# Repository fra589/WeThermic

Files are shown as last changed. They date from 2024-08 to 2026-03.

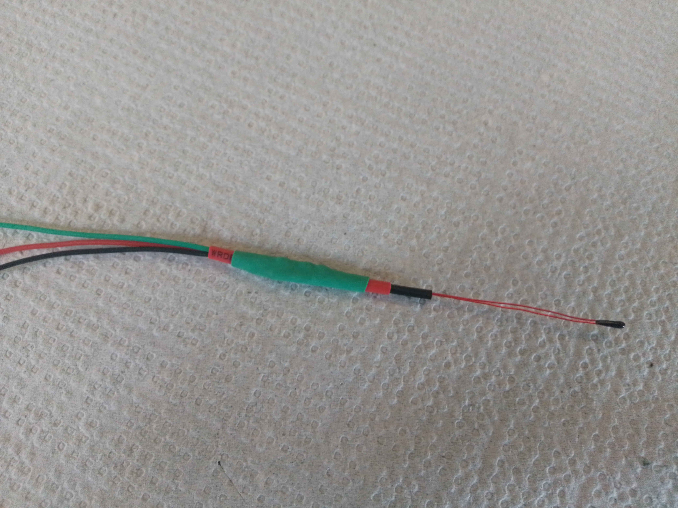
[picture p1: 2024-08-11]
images/IMG_20240811_103702.jpg

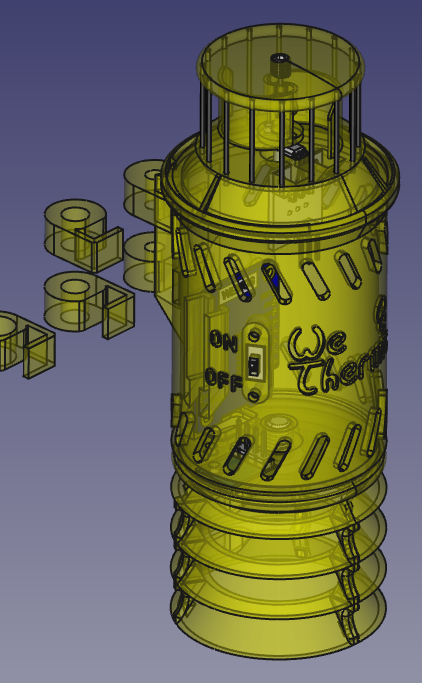
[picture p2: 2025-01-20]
images/freecad02.png

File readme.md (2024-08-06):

<h1 align='center'>WeThermic Free Flight Thermal Detector</h1>
<p>
Station météo indiquant la vitesse du vent, la température et la pression atmosphérique ainsi que l'affichage des courbes correspondantes sur un navigateur web, via un réseau WiFi, pour aider à la détection d'ascendances thermiques en modèle réduit de vol libre.
</p>
<p>
Weather station indicating wind speed, temperature and atmospheric pressure as well as displaying the corresponding curves on a web browser, via a WiFi network, to help detect thermal ascents in free flight model aircraft.  
</p>
<table>
<tr>
<td>
<b>Matériel utilisé :</b>
<ul>
<li>Boitier imprimé en 3D,</li>
<li>1 x Carte microcontrôleur WiFi ESP8266 Wemos D1 mini,</li>
<li>1 x Capteur de vent :</li>
<ul>
<li>2 x Aimants néodyme Ø2x2,</li>
<li>1 x Capteur à effet Hall KY-003,</li>
</ul>
<li>1 x Capteur de température et pression Bosch BMP180,</li>
<li>1 x Termistance 10K MF52B B3435 1%,</li>
<li>1 x Résistance 10KΩ 1/4W 1%,</li>
<li><s>1 x écran OLED I2C SSD1306, 0.96 Pouce, 128 x 64 Pixel.</li></s></li>
</ul>
</td>
<td>
<b>Hardware:</b>
<ul>
<li>3D printed case</li>
<li>1 x Wemos D1 mini ESP8266 WiFi microcontroller card,</li>
<li>1 x Wind sensor:</li>
<ul>
<li>2 x Ø2x2 neodymium magnets,</li>
<li>1 x Hall effect sensor KY-003,</li>
</ul>
<li>1 x Bosch BMP180 temperature and pressure sensor,</li>
<li>1 x Termistor 10K MF52B B3435 1%,</li>
<li>1 x Resistance 10KΩ 1/4W 1%,</li>
<li><s>1 x I2C SSD1306 OLED screen, 0.96 Inch, 128x64 Pixel.</s></li>
</ul>
</td>
</tr>
<tr>
<td>
<b>Prérequis logiciels :</b>
<p><br />
Pour construction à partir des sources :
<ul>
<li><a href="https://www.arduino.cc/en/software">Environnement de développement Arduino v1.8.19</a>,</li>
<ul>
<li><a href="https://github.com/esp8266/Arduino">Noyau Arduino pour puce WiFi ESP8266</a>,</li>
<li><a href="https://github.com/earlephilhower/arduino-esp8266littlefs-plugin">Téléchargeur système de fichiers ESP8266 LittleFS</a>,</li>
<li><s><a href="https://github.com/adafruit/Adafruit_SSD1306">Adafruit_SSD1306</a>,</s></li>
<li><a href="https://github.com/sparkfun/BMP180_Breakout_Arduino_Library">BMP180_Breakout_Arduino_Library </a>,</li>
</ul>
</p>
</ul>
<p>
Flashage a partir des realeases binaires (Windows only):
<ul>
<li><a href="https://www.espressif.com/en/support/download/other-tools">Flash Download Tools</a>,</li>
<li><a href="https://github.com/fra589/WeThermic/releases">Dernier firmware (WeThermic.firmware_v<span>_X.Y.ZZZZZZ</span>.bin)</a></li>
<li><a href="https://github.com/fra589/WeThermic/releases">Dernière application (WeThermic.application_v<span>_X.Y.ZZZZZZ</span>.bin)</a></li>
</ul>
</p>
</td>
<td>
<b>Requisites software:</b>
<p><br />
To build from sources:
<ul>
<li><a href="https://www.arduino.cc/en/software">Arduino ide v1.8.19</a>,</li>
<ul>
<li><a href="https://github.com/esp8266/Arduino">Arduino core for ESP8266 WiFi chip</a>,
<li><a href="https://github.com/earlephilhower/arduino-esp8266littlefs-plugin">Arduino ESP8266 LittleFS Filesystem Uploader</a>,</li>
<li><s><a href="https://github.com/adafruit/Adafruit_SSD1306">Adafruit_SSD1306</a>,</s></li>
<li><a href="https://github.com/sparkfun/BMP180_Breakout_Arduino_Library">BMP180_Breakout_Arduino_Library </a>,</li>
</ul>
</p>
</ul>
<p>
To flash from binary realeases (Windows only):
<ul>
<li><a href="https://www.espressif.com/en/support/download/other-tools">Flash Download Tools</a>,</li>
<li><a href="https://github.com/fra589/WeThermic/releases">Latest firmware (WeThermic.firmware_v<span>_X.Y.ZZZZZZ</span>.bin)</a></li>
<li><a href="https://github.com/fra589/WeThermic/releases">Latest application (WeThermic.application_v<span>_X.Y.ZZZZZZ</span>.bin)</a></li>
</ul>
</p>
</td>
</tr>
</table>
<p>
Développement en cours, de nouvelles version possibles à tout moment, pas forcément sans bugs :-)
</p>
<p>
Development in progress, new versions possible at any time, not necessarily without bugless :-)
</p>
<p align='center'>
<a href='https://github.com/fra589/WeThermic/wiki'><B>Wiki documentation in progress...</B></a>
</p>

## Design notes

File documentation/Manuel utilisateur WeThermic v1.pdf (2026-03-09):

## Version 1.0

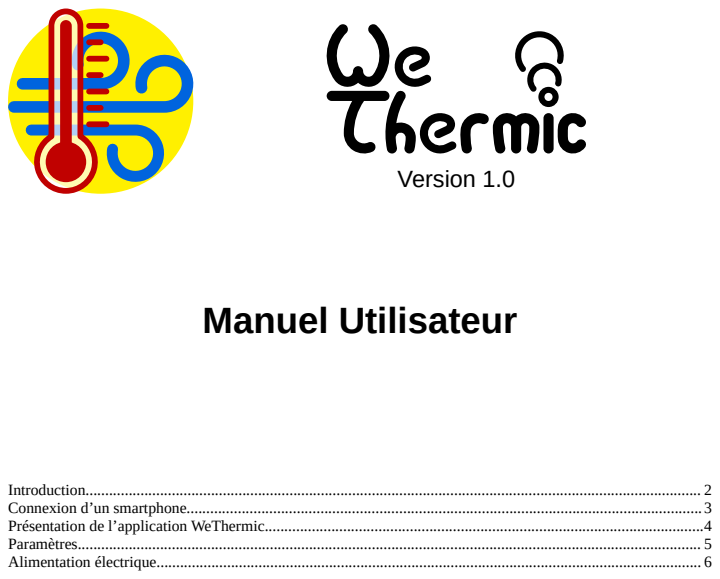
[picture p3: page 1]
Manuel Utilisateur

## Introduction

Le projet WeThermic est un projet visant à créer une station météo capable d’aider les aéromodélistes pratiquant le vol libre dans la détection des ascendances.
La station météo WeThermic utilise des éléments bon marché et facile à se procurer et ne nécessitant pas de travaux important et/ou compliqués d’un point de vue des compétences en électronique.
La station météo est capable de fournir les courbes de vitesse du vent, température et pression atmosphérique sur une durée de 5, 10 ou 20 minutes avec une résolution respectivement de 0,5, 1 ou 2 secondes.
Les courbes peuvent être affichées avec un smartphone, une tablette ou tout autre équipement informatique capable de se connecter au point d’accès wifi que constitue la station, et de communiquer avec elle au travers un navigateur web.

## Connexion d’un smartphone

Les copies d’écran de cette notice ont été réalisées à l’aide d’un téléphone sous Android version 13. Cela peut ne pas correspondre exactement à votre téléphone, en cas de différences, se référer à la documentation de votre téléphone ou équipement.

Sur votre téléphone, ouvrez l’écran de configuration du wifi.
Quelques instant après avoir alimenté la station météo, vous devriez la voir apparaître dans la liste des réseaux disponibles (Figure 1).
Le nom par défaut (SSID) de la station est « WeThermic_XX:XX:XX ». Ou XX:XX:XX est un code unique dépendant du processeur wifi de la carte. Par défaut, il s’agit d’un réseau wifi « ouvert » qui n’utilise pas de mot de passe pour se connecter.

Cliquez sur le SSID pour connecter votre téléphone à la station météo.
Lors de la connexion, le téléphone indique une connectivité limitée. Ce comportement est normal, dans la mesure ou la connexion wifi vers la station ne permet pas l’accès à Internet.
Cliquez sur le message qui indique la connexion limitée pour forcer la connexion même sans Internet (Figure 2), puis, validez le message qui s’affiche (Figure 3).
Vous pouvez également cocher la case « Ne plus demander pour ce réseau » afin que vos futures connexions se fassent directement.

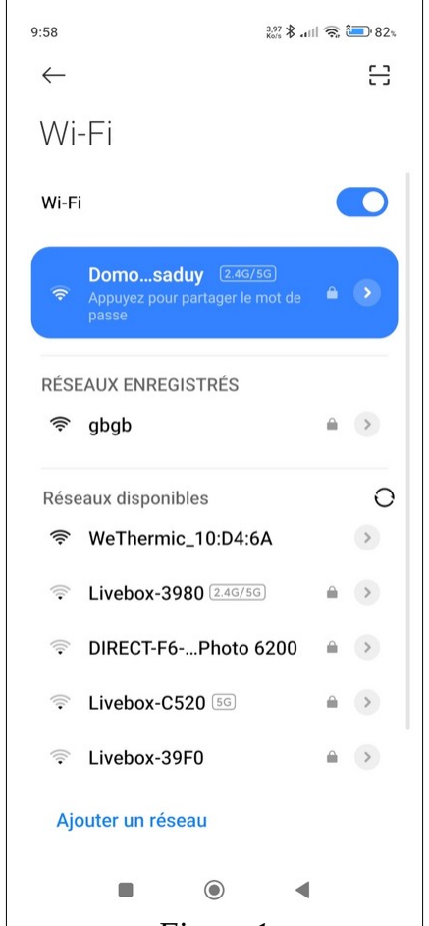
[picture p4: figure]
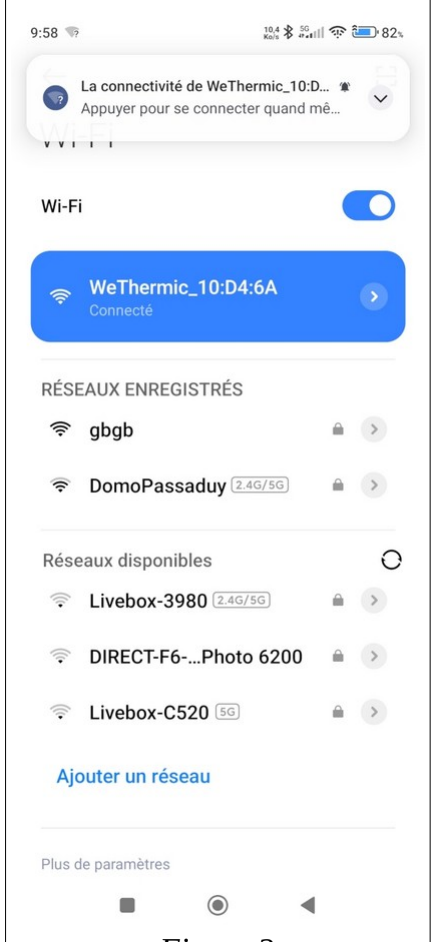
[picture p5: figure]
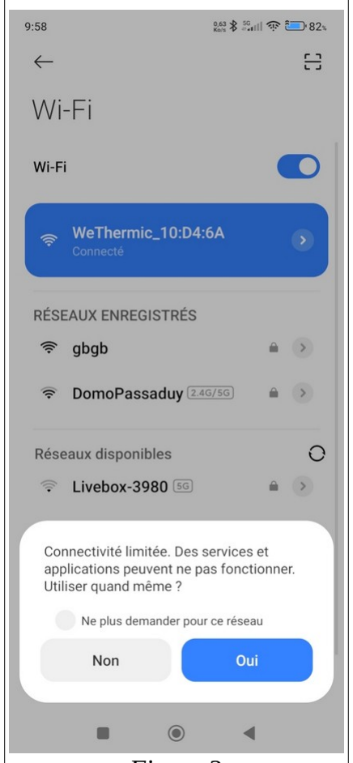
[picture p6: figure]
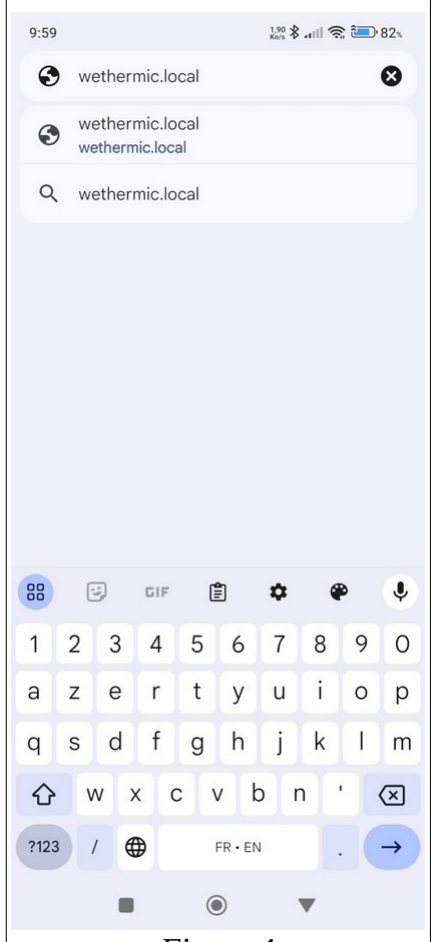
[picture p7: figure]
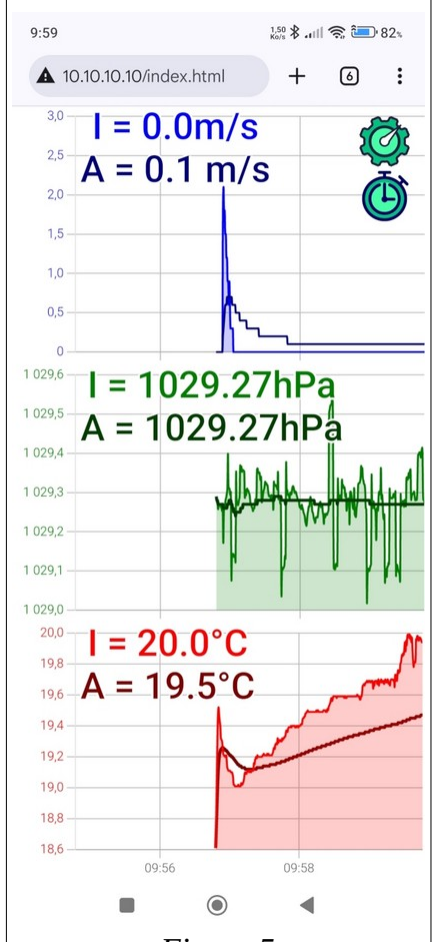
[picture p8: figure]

Une foi le wifi connecté, ouvrez votre navigateur Internet (Google Chrome par exemple) et tapez dans la barre d’adresse(Figure 4) :
http://wethermic.local

Le navigateur affiche maintenant la page d’accueil de la minuterie (Figure 5). Il est possible également, dans le cas ou le nom ne fonctionne pas avec votre smartphone, d’utiliser l’adresse IP : http://10.10.10.10 pour se connecter à la station.
Ajout d’une icône sur l’écran d’accueil de votre smartphone :

Cliquez sur les 3 points en haut à droite de l’écran du navigateur Google Chrome, puis, dans le menu qui s’ouvre, cliquez sur « Ajouter à l’écran d’accueil ».

Cette action ajoutera une icône d’accès directe au programme de la station météo sur votre écran d’accueil.

Figure 1 | Figure 2 | Figure 3 | Figure 4 | Figure 5

## Présentation de l’application WeThermic

Écran principal :

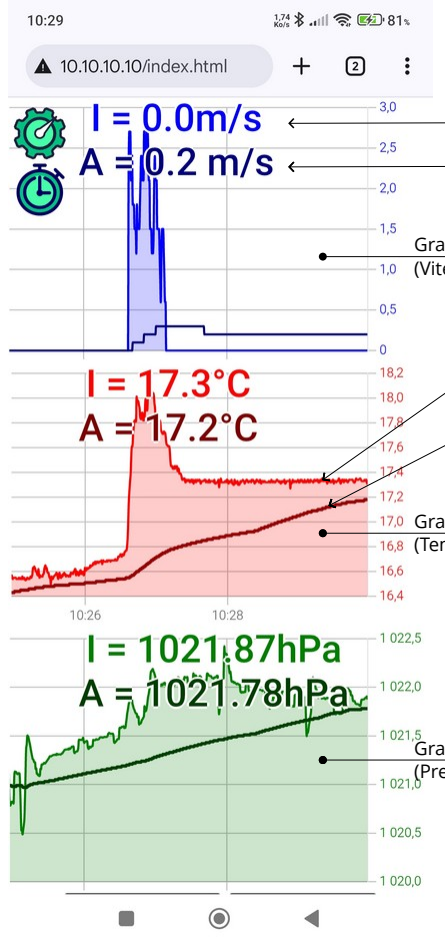
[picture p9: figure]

Faites glisser vers le haut permet de faire apparaître les 2 boutons suivants :

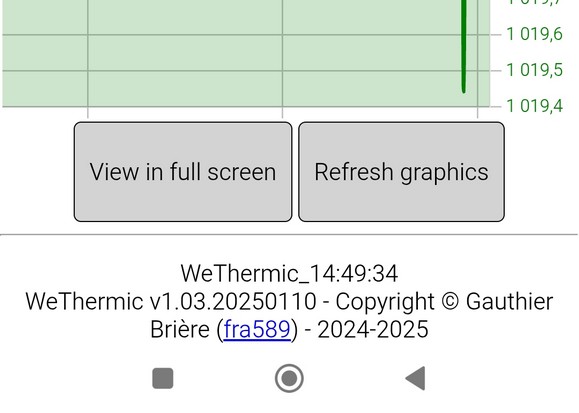
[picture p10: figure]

« View in full screen » : Bascule l’affichage en mode « plein écran ».

« Refresh graphics » : Recalcule et rafraîchi l’affichage de l’écran.

Un clic sur l’icône Permet d’afficher un compte à rebours de la fin du round. La valeur par défaut du compte à rebours est fixée à 7 minutes (durée standard d’un round de flyoff) :

Cliquez sur « | » pour démarrer le compte à rebours. Cliquez sur « | » pour l’arrêter.
Les icônes « | » et « | » qui s’affichent en même temps que le compte à rebours permettent de
désactiver ou d’activer un bip sonore qui marque toutes les minutes pendant le décompte du temps.

Graphique 1 (Upper graph)
(Vitesse du vent m/s par défaut)

Graphique 2 (Middle graph) (Température °C par défaut)

Graphique 3 (Bottom graph)
(Pression athmospherique (hPa) par défaut)

I : Valeur instantanée
A : Valeur moyenne

Courbe valeurs
insantanées
Courbe valeurs
moyennes

## Paramètres

Cliquez sur l’icône pour accéder à l’écran de paramétrage :

Les icônes en haut de l’écran de paramétrage servent à :

Fermer l’écran des paramètres,
Redémarrer la station météo,
Restaurer les paramètres d’origine par défaut de la station et de l’application.
- Au niveau du thème de couleur, vous pouvez choisir entre un thème foncé ( | )
ou un thème clair ( | ).

Cliquer sur les ronds de couleur permet de modifier la couleur des
éléments de manière indépendante :

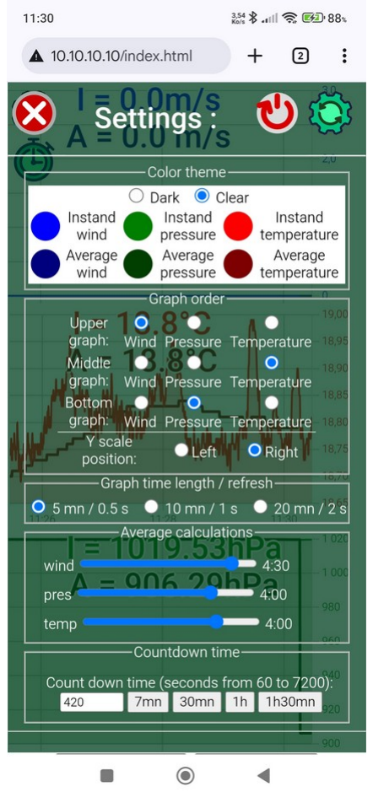
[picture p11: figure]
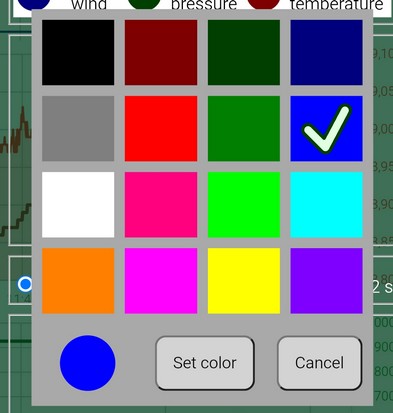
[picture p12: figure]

- Le cadre suivant « Graph order » permet de choisir l’ordre d’affichage des graphiques « Wind » (vent),
« Pressure » (pression atmosphérique) et « Temperature » (température) sur le graphique du haut, du milie ou du bas.
« Yscale position » « Left » / « Right » permet un chois de position des grilles d’échelle des graphiques respectivement à gauche ou à droite.

Le paramètre « Graph time length / refresh » définit la durée du graphique affichées, au choix :
- 5 minutes avec un taux de rafraîchissement de 0,5 seconde,
- 10 minutes avec un taux de rafraîchissement de 1 seconde,
- 20 minutes avec un taux de rafraîchissement de 2 seconds.

« Average calculations » permet de choisir la durée sur laquelle sont calculées les valeurs de la courbe moyenne. Cette durée est définie indépendamment pour chaque courbe wind (vent), pres (pression atmosphérique) ou temp (température). Les valeurs admises vont de 30 secondes à 5 minutes par pas de 30 secondes.

Le cadre « Countdown time » permet de définir la durée du compte à rebours. La zone de texte à gauche permet de saisir n’importe quelle valeur, exprimées en secondes. Les boutons à droite de cette zone de texte permettent d’entrer directement les valeur standards de 7 minutes, 30 minutes, 1 heure ou 1 heure et demi.

Faire glisser l’affichage vers le haut permet d’accéder à la configuration du réseau wifi de la station météo :

La première zone de texte n haut correspond à la définition du nom de la station (SSID du réseau wifi).
Les 2 zones de texte suivante permettent d’entrer un mot de passe pour sécuriser l’accès a ce réseau.
L’icône | / | affiche / masque le mot de passe entré.
Cliquer sur | | pour valider vos changements.

La zone tout en bas permet de gérer la connexion de la station à un autre réseau wifi.

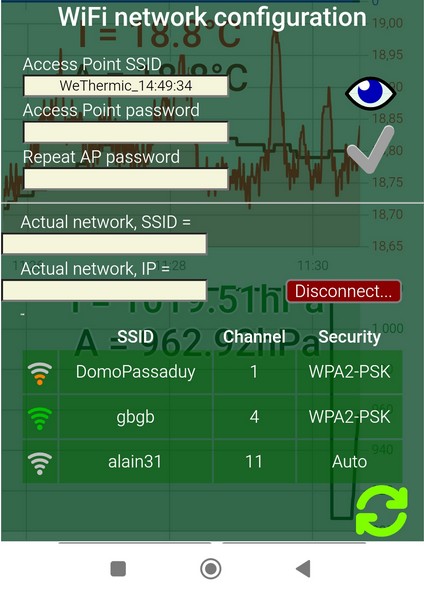
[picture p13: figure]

Les zones de texte « Actual network SSID » et « Actual network IP » affichent respectivement le nom du réseau et l’adresse IP de la station sur le réseau si la station est connectée à un réseau externe.

Si la station n’est pas connectée à un réseau externe, ces deux zones de texte sont vide.
Dans le cas ou la station est connectée à un réseau externe, il est possible d’utiliser l’application à partir de n’importe quel autre ordinateur, tablette ou téléphone connecté au même réseau en utilisant le lien :
« http://wethermic.local » dans un navigateur web.
Si la station est connectée à un réseau externe, le nom du réseau ainsi que le mot de passent sont sauvegardés, même si la station est redémarrée ou éteinte. Dans ce cas, la station essaiera de se reconnecter à ce réseau à chaque démarrage.
Toujours dans le cas ou la station est connectée à un réseau externe, cliquer sur le bouton « Disconnect » entraîne la déconnexion ainsi que l’oubli du réseau.
La liste des réseaux accessibles est affichée en dernier.
Cliquez sur le nom d’un réseau pour connecter la station. Un mot de passe vous est demandé en cas de réseau sécurisé.
Si la connexion au réseau est réussie, celui-ci sera mémorisé et la station essaiera s’y connecter à chaque démarrage.

## Alimentation électrique

L’alimentation de la station s’effectue à l’aide d’une batterie LiPo de 3,7 volts (1S).
Une batterie de 1000 mAh permet un usage continu d’environ 8 heures.
Débrancher la batterie de la station pour la recharger à l’aide d’un chargeur externe ad-hoc.

La station sera alimentée en cas de connexion à un ordinateur par l’intermédiaire de la prise micro USB de sa carte processeur. Cela peut être nécessaire pour charger une mise à jour du logiciel ou en cas de débogage. Dans ce cas, débrancher impérativement la batterie !

Ne jamais utiliser la prise USB de la carte processeur de la station pour recharger la batterie ! Cela risquerait de provoquer sa destruction et même entraîner un incendie.

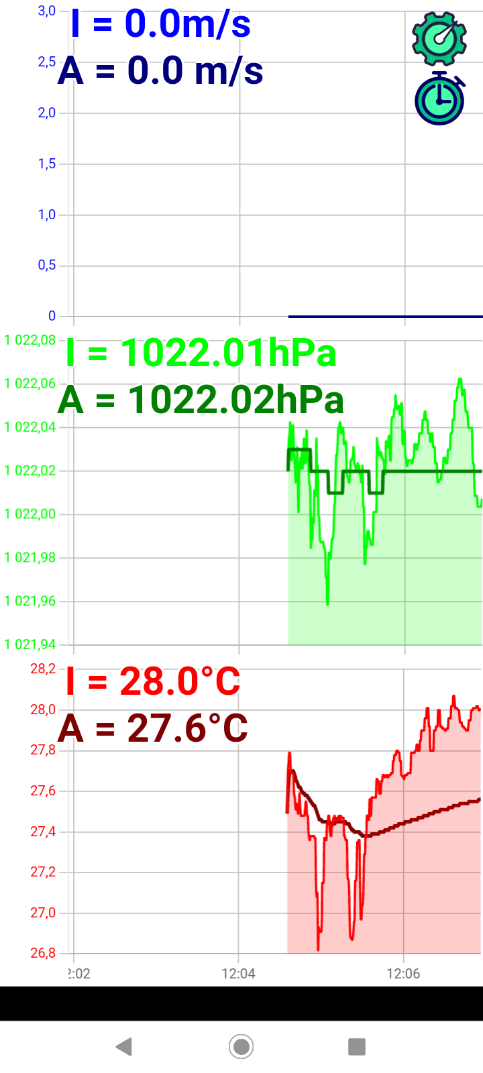
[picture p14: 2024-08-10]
images/Screenshot_20240806-120704.png

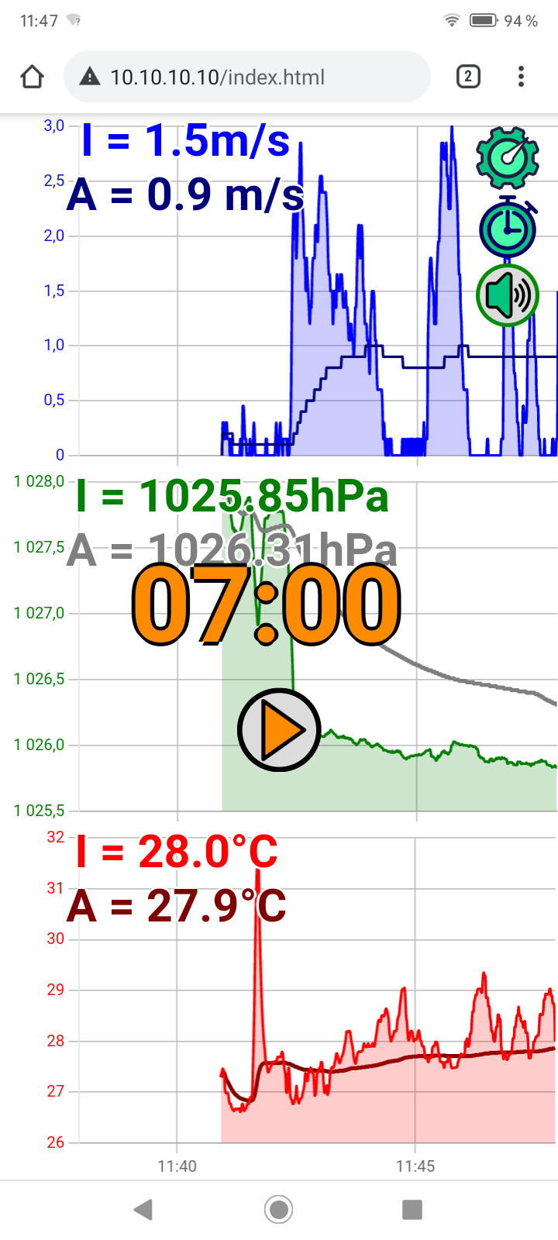
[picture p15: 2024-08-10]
images/Screenshot_20240810-114803.png

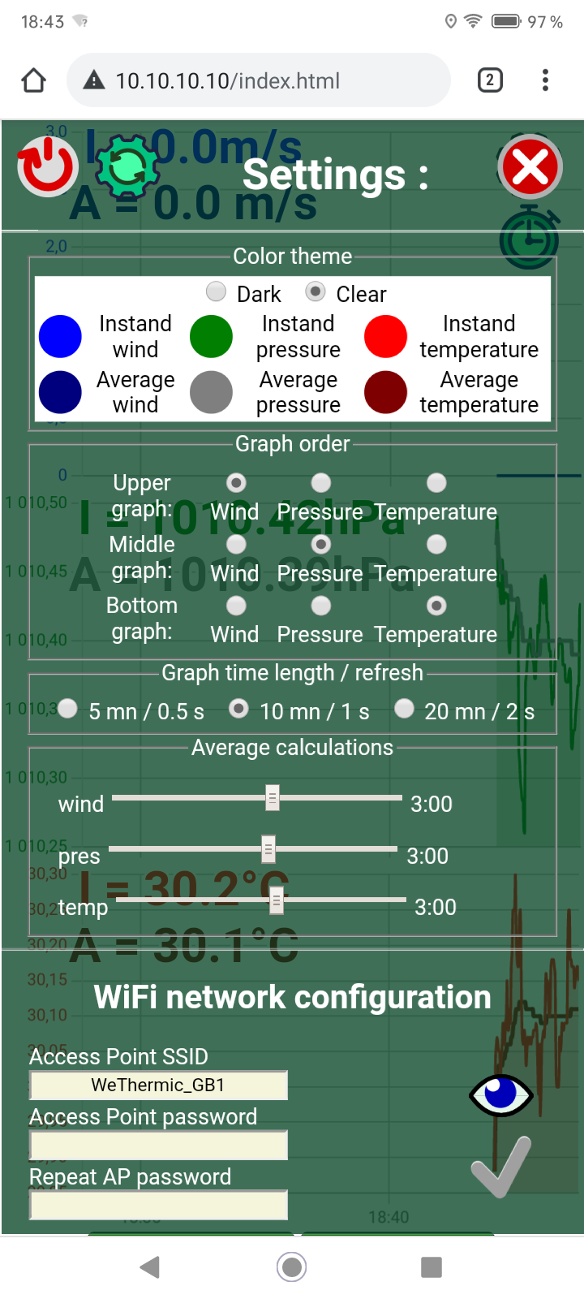
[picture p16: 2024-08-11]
images/Screenshot_20240811-184357.png

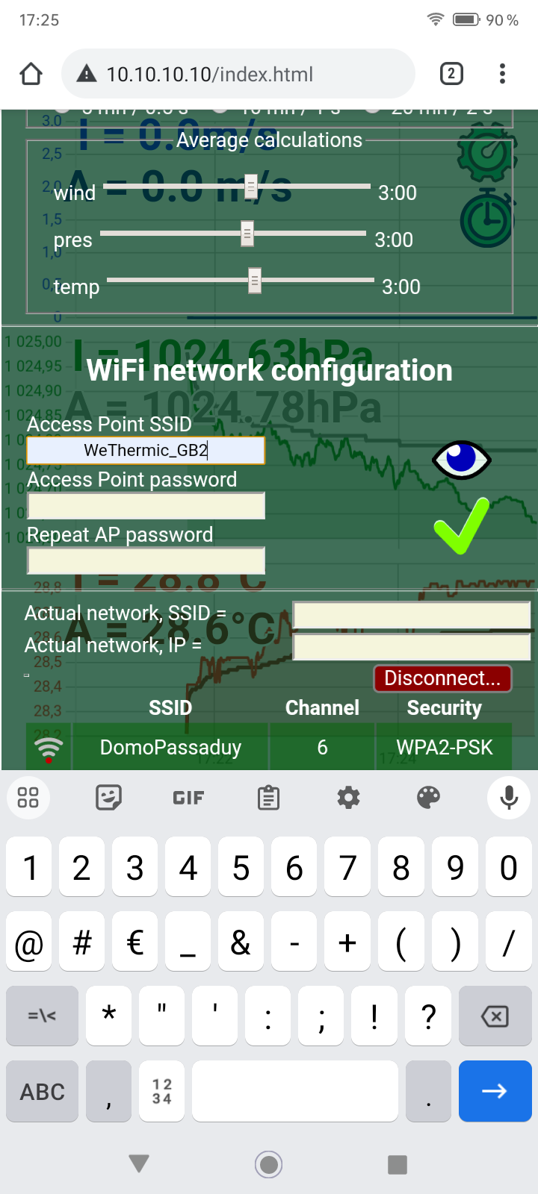
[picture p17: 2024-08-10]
images/Screenshot_20240810-172537.png

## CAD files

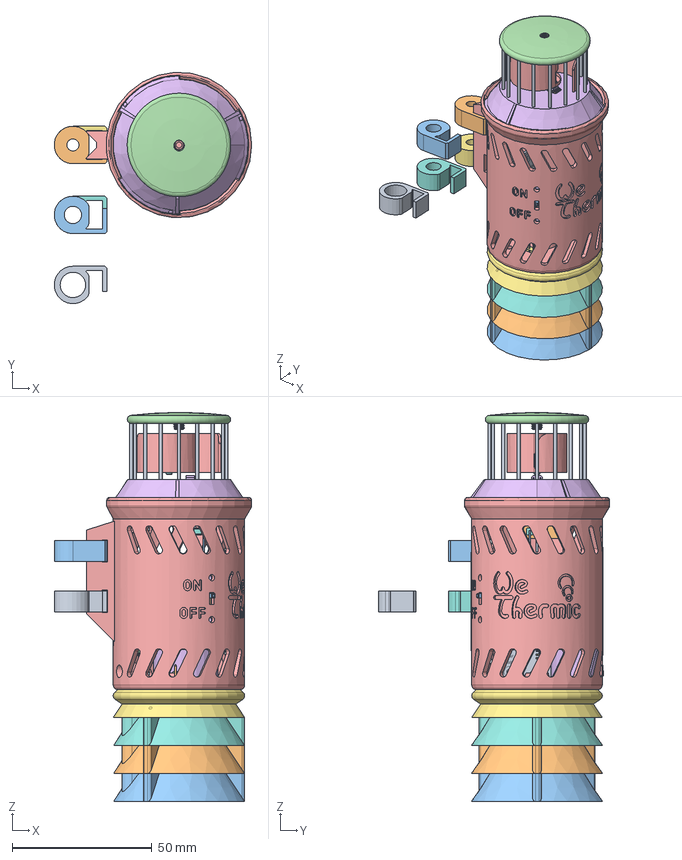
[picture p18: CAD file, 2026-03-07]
FreeCAD/WeThermic.FCStd
70.6 x 82.6 x 139.0 mm
WEMOS_D1_MINI_V_3_0_0_PCB_180112_01
WEMOS_D1_MINI_V_3_0_0_PUSH_BUTTON_180111_01
QFN_32_1EP_5x5mm_Pitch0_5mm_step1_01
SOIJ_8_5_3x5_3mm_Pitch1_27mm_step1_01
ABM8_STEP1_01
_050170001_stp1_01
SOIC_16_3_9x9_9mm_Pitch1_27mm_step1_01
aimants
barreaux
juppeInf001
juppeInf002
chapeau
boitier
socle
juppeSup
juppeInf
axe
palierInf
r-smd-0603
c-smd-0603
PinHeader
PinHeader001
PinHeader002
PinHeader003
PinHeader004
SOT23SMD v1
SOT23SMD v002
SOT23SMD v003
SOT23SMD v004
c-smd-0604
r-smd-0604
c-smd-0605
BMP180
PalierSup
brideSwitch
fixationD1
fixationD2
fixationD3
fixationD1.001
fixationD2.001
rotor
fixeBatterie

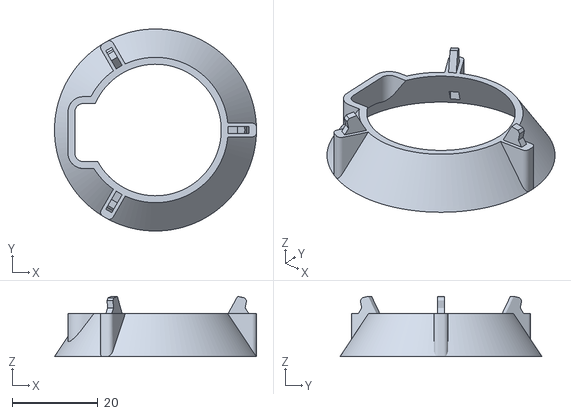
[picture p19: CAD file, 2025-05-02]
FreeCAD/WeThermic-juppeInf.stl
47.0 x 47.0 x 14.0

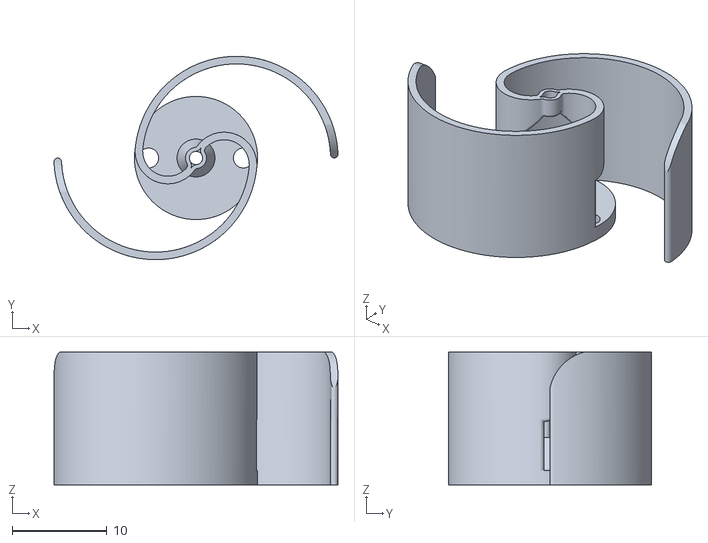
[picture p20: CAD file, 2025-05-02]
FreeCAD/WeThermic-rotor.stl
30.0 x 21.5 x 14.0

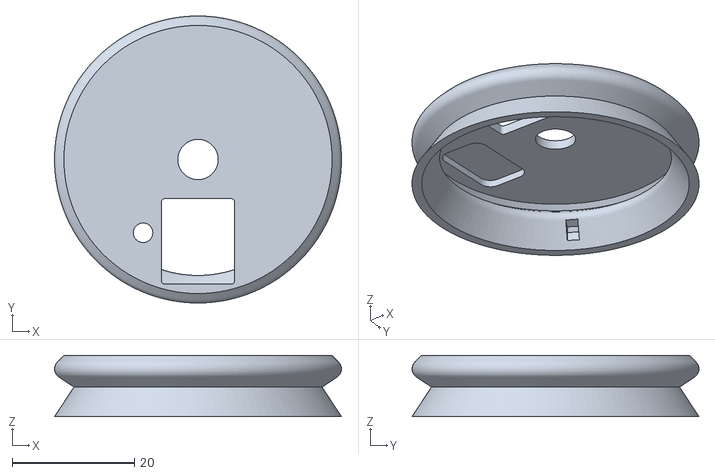
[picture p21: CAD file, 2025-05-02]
FreeCAD/WeThermic-juppeSup.stl
47.0 x 47.0 x 10.0

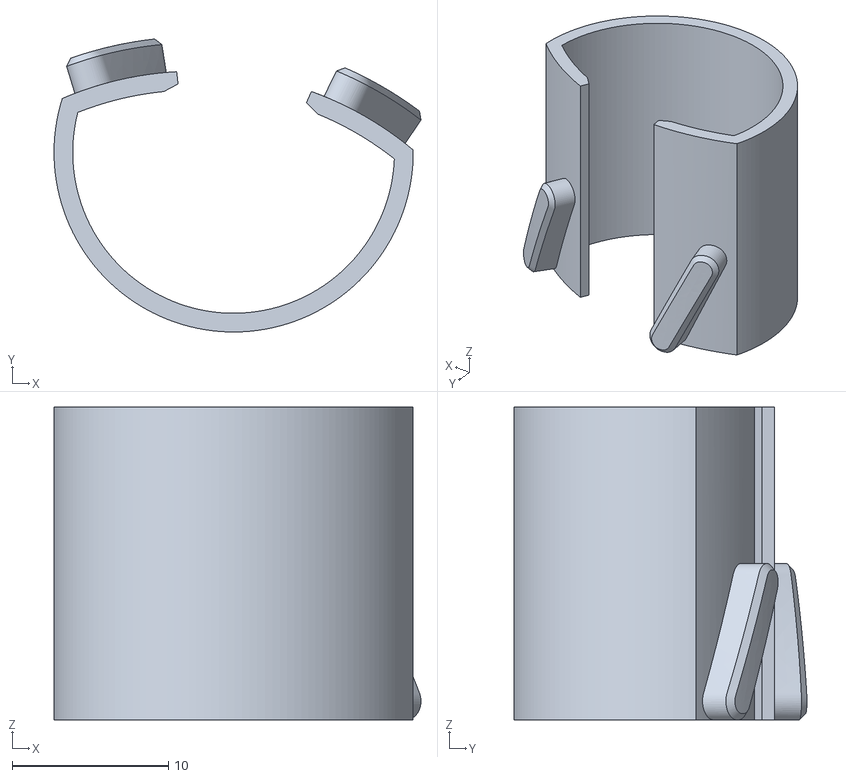
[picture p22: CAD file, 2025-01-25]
FreeCAD/WeThermic-fixeBatterie.stl
23.5 x 18.7 x 20.0

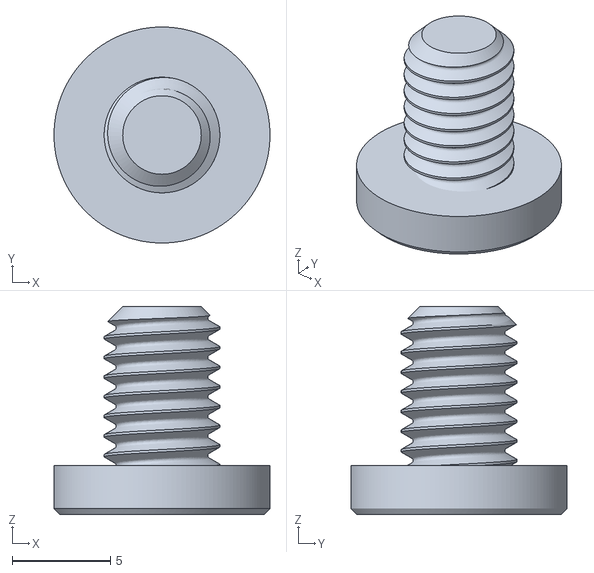
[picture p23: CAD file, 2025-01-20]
FreeCAD/WeThermic-vis.stl
11.0 x 11.0 x 10.6

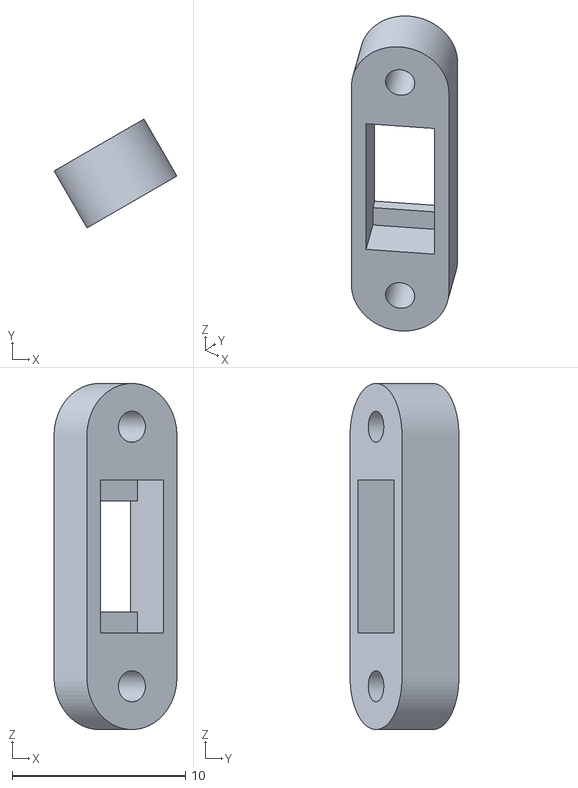
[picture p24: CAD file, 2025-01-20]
FreeCAD/WeThermic-brideSwitch.stl
7.10 x 6.29 x 20.0

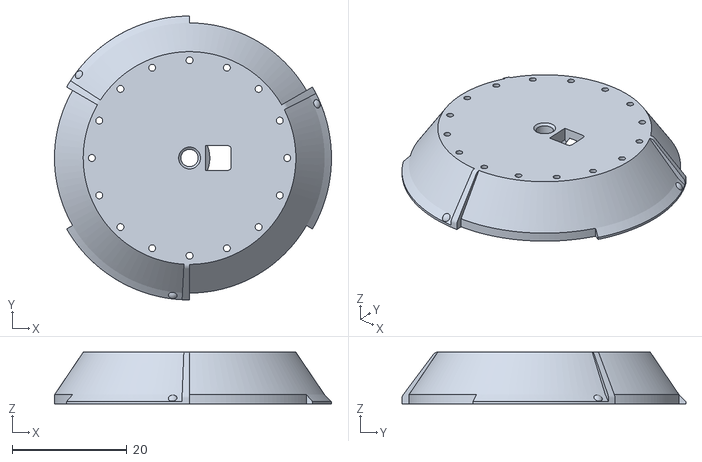
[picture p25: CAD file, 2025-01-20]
FreeCAD/WeThermic-socle.stl
48.2 x 49.4 x 9.00

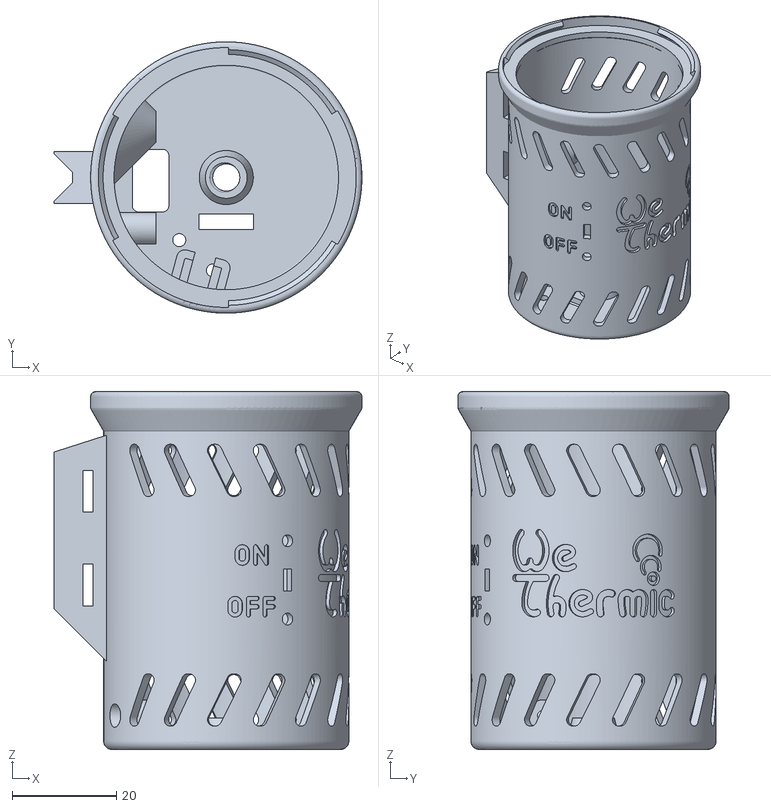
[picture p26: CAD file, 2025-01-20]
FreeCAD/WeThermic-boitier.stl
59.0 x 52.0 x 68.6

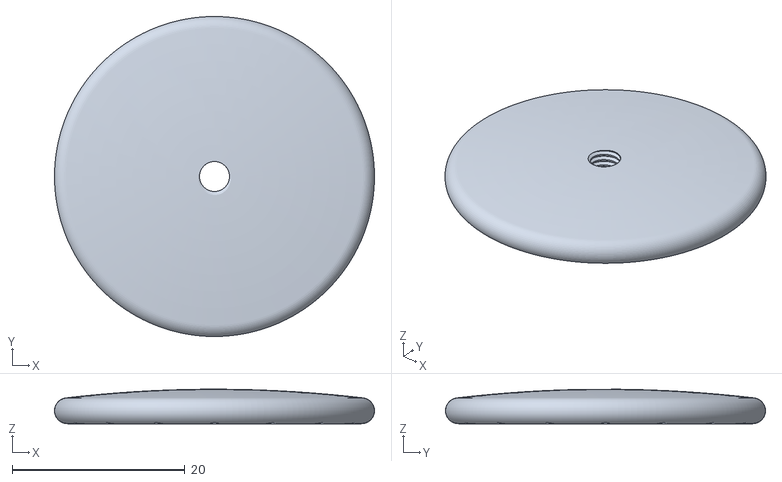
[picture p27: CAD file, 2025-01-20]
FreeCAD/WeThermic-chapeau.stl
37.0 x 37.0 x 3.99

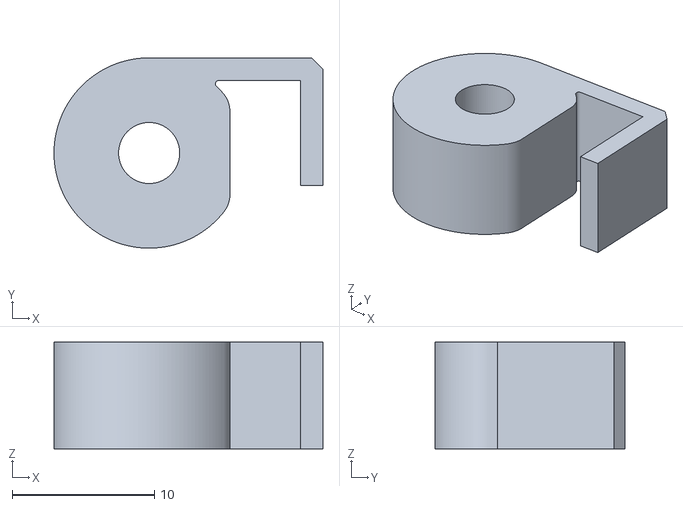
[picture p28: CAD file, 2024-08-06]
FreeCAD/WeThermic-fixationD1.stl
18.9 x 13.4 x 7.50

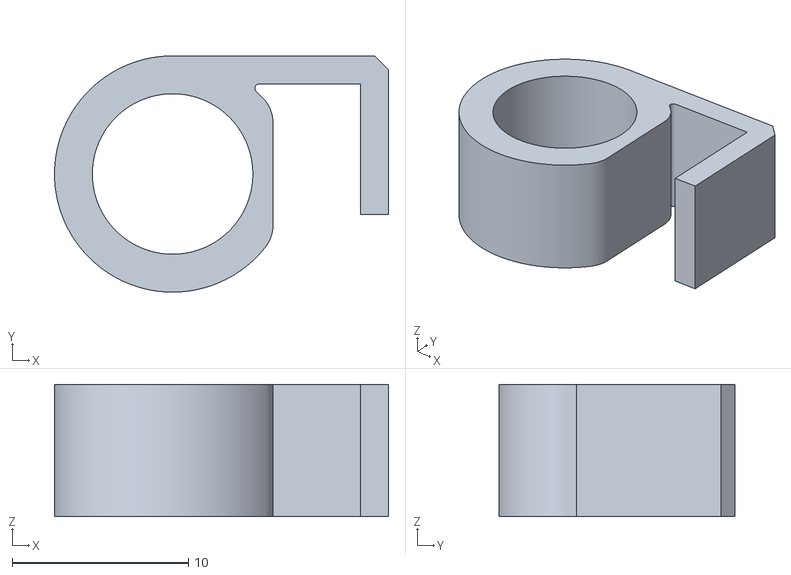
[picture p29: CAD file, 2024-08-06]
FreeCAD/WeThermic-fixationD3.stl
18.9 x 13.4 x 7.50

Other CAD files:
FreeCAD/WeThermic-fixationD2.stl

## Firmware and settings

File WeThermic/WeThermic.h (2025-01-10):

/****************************************************************************/
/*                                                                          */
/* Copyright (C) 2024-2025 Gauthier Brière (gauthier.briere "at" gmail.com) */
/*                                                                          */
/* This file: WeThermic.h is part of WeThermic                              */
/*                                                                          */
/* WeThermic is free software: you can redistribute it and/or modify it     */
/* under the terms of the GNU General Public License as published by        */
/* the Free Software Foundation, either version 3 of the License, or        */
/* (at your option) any later version.                                      */
/*                                                                          */
/* WeThermic is distributed in the hope that it will be useful, but         */
/* WITHOUT ANY WARRANTY; without even the implied warranty of               */
/* MERCHANTABILITY or FITNESS FOR A PARTICULAR PURPOSE.  See the            */
/* GNU General Public License for more details.                             */
/*                                                                          */
/* You should have received a copy of the GNU General Public License        */
/* along with this program.  If not, see <http://www.gnu.org/licenses/>.    */
/*                                                                          */
/****************************************************************************/

#ifndef WeThermic_h
  #define WeThermic_h

  #define DEBUG
  #define DEBUG_WEB
  //#define DEBUG_INTERRUPT
  //#define DEBUG2
  //#define DEBUG3
  //#define DEBUG_PROBE

  // Screen SSD1306 disabled by default
  //#define HAVE_SCREEN
  
  // define GENERATE_204 to reply to Google Internet verification 
  // and avoid automatic captive portal redirection on android
  // Comment next line if you want the automatic redirection
  #define GENERATE_204
  
  #include <EEPROM.h>
  #include <ESP8266WiFi.h>
  #include <ESP8266mDNS.h>
  #include <ESP8266WebServer.h>
  #include <DNSServer.h>
  #include <LittleFS.h>
  #ifdef HAVE_SCREEN
    #include <Adafruit_SSD1306.h>
  #endif
  #include <SFE_BMP180.h>

  #include "WeThermicLogo.h"
  #include "eeprom.h"
  #include "wwwifi.h"
  #include "webserver.h"
  #ifdef HAVE_SCREEN
    #include "affichage.h"
  #endif
  #include "sfe_bmp180.h"
  #include "thermistance.h"

  #define ORG_NAME              "fra589"
  #define COPYRIGHT             "G.Brière 2023-2025"
  #define APP_NAME              "WeThermic"
  #define APP_VERSION_MAJOR     "1"
  #define APP_VERSION_MINOR     "03"
  #define APP_VERSION_DATE      "20250110"
  #define APP_VERSION_STRING    "v" APP_VERSION_MAJOR "." APP_VERSION_MINOR "." APP_VERSION_DATE
  #define APP_NAME_VERSION      APP_NAME " - " APP_VERSION_STRING "\0"

  // Paramètres mesure du vent
  #define HALL_PIN D5 // Entrée numérique esp8266
  #define COEF_VENT 0.3
  extern volatile uint32_t pulse;
  extern float vent;
  
  // Mesure température et pression
  extern float tempBmp180;
  extern float pression;
  // Thermistor
  #define CTN_PIN A0
  extern float tempCtn;

  // Stockage 5 minutes de mesures à 500ms d'interval => duree = 500,
  // 10 minutes à 1 seconde d'interval => duree = 1000,
  // 20 minutes à 2 seconde d'interval => duree = 2000.
  extern uint32_t duree;
  #define DEFAULT_DUREE 500   // Durée de comptage RPM (ms) par defaut

  // Taille du tableau pour stocker toute les mesure pendant 
  // 5 minutes avec un interval de "DUREE" millisecondes.
  #define DUREE_HISTORIQUE 600 // ( 5 * 60 / ( DUREE / 1000 ) )
  extern float histVent[DUREE_HISTORIQUE];
  extern float histBmp180[DUREE_HISTORIQUE];
  extern float histPression[DUREE_HISTORIQUE];
  extern float histTempCtn[DUREE_HISTORIQUE];
  extern uint32_t idxHistorique;

  // Paramètres WiFi 
  #define DEFAULT_AP_SSID    "WeThermic_" // SSID de l'AP balance
  #define DEFAULT_AP_PWD     ""           // WPA-PSK/WPA2-PSK AP
  #define DEFAULT_CLI_SSID   ""           // SSID client (la balance se connecte si défini)
  #define DEFAULT_CLI_PWD    ""           // WPA-PSK/WPA2-PSK client
  #define DEFAULT_AP_CHANNEL 3

  // Variable globales pour le WiFi
  #define MAX_SSID_LEN 32 // Longueur maxi d'un SSID
  #define MAX_PWD_LEN  63 // Longueur maxi des mots de passe WiFi
  extern char cli_ssid[MAX_SSID_LEN];
  extern char cli_pwd[MAX_PWD_LEN];
  extern char ap_ssid[MAX_SSID_LEN];
  extern char ap_pwd[MAX_PWD_LEN];

  // Adresses EEProm pour sauvegarde des paramètres
  #define EEPROM_LENGTH 512
  #define ADDR_AP_SSID         0 //   0 + 32 =  32
  #define ADDR_AP_PWD         32 //  32 + 63 =  95
  #define ADDR_CLI_SSID       95 //  95 + 32 = 127
  #define ADDR_CLI_PWD       127 // 126 + 63 = 190
  #define ADDR_DUREE         190 // 190 +  4 = 194

  // Web server
  extern ESP8266WebServer server;

  #ifdef HAVE_SCREEN
    // Pour mise en veille de l'affichage
    extern uint8_t affichage_on;
    extern long debutCompteurVeille;
    #define DELAY_VEILLE 300000 // 300 secondes (5 minutes)
  #endif

  // DNS server
  extern DNSServer dnsServer;
  #define DNS_PORT 53
  
  // hostname pour mDNS. devrait fonctionner au moins avec windows :
  // http://WeThermic.local
  extern const char *myHostname;

  // Fichiers web
  #define ROOT_FILE "/index.html"
  #define PWD_FILE  "/knownWiFi.xml"
  #define TMP_FILE  "/tmp.xml"

#endif

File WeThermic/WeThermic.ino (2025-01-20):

/****************************************************************************/
/*                                                                          */
/* Copyright (C) 2024-2025 Gauthier Brière (gauthier.briere "at" gmail.com) */
/*                                                                          */
/* This file: WeThermic.ino is part of WeThermic                            */
/*                                                                          */
/* WeThermic is free software: you can redistribute it and/or modify it     */
/* under the terms of the GNU General Public License as published by        */
/* the Free Software Foundation, either version 3 of the License, or        */
/* (at your option) any later version.                                      */
/*                                                                          */
/* WeThermic is distributed in the hope that it will be useful, but         */
/* WITHOUT ANY WARRANTY; without even the implied warranty of               */
/* MERCHANTABILITY or FITNESS FOR A PARTICULAR PURPOSE.  See the            */
/* GNU General Public License for more details.                             */
/*                                                                          */
/* You should have received a copy of the GNU General Public License        */
/* along with this program.  If not, see <http://www.gnu.org/licenses/>.    */
/*                                                                          */
/****************************************************************************/

/****************************************************************************/
/*                                                                          */
/* Commande pour compiler et uploader :                                     */
/*                                                                          */
/* /home/gauthier/Logiciels/arduino-1.8.19/arduino \                        */
/* --upload                                                                 */
/* --verbose                                                                */
/* --preserve-temp-files                                                    */
/* --board esp8266:esp8266:d1_mini_clone                                    */
/* --port /dev/ttyUSB0                                                      */
/* /home/gauthier/src/WeThermic/WeThermic/WeThermic.ino                     */
/*                                                                          */
/****************************************************************************/

#include "WeThermic.h"


//----------------------------------------------------------------------------
// Variables globales
//----------------------------------------------------------------------------

// Mesure du vent
long mesure = 0;
bool sup_seuil = false;
uint32_t temps0 = millis();
uint32_t temps1 = millis();
volatile uint32_t pulse = 0;
float vent = 0;
// Mesure températures et pression
float tempBmp180 = 0;
float pression = 0;
float tempCtn = 0;
float temperatureCumule;
long   nombreTemperature = 0;
// Stockage 5 minutes de mesures à 500ms ou 10 minutes à 1 seconde d'interval :
uint32_t duree = DEFAULT_DUREE;
float histVent[DUREE_HISTORIQUE]     = {0};
float histBmp180[DUREE_HISTORIQUE]   = {0};
float histPression[DUREE_HISTORIQUE] = {0};
float histTempCtn[DUREE_HISTORIQUE]  = {0};
uint32_t idxHistorique = 0;
// WiFi
char cli_ssid[MAX_SSID_LEN] = DEFAULT_CLI_SSID;
char cli_pwd[MAX_PWD_LEN]   = DEFAULT_CLI_PWD;
char ap_ssid[MAX_SSID_LEN]  = DEFAULT_AP_SSID;
char ap_pwd[MAX_PWD_LEN]    = DEFAULT_AP_PWD;

// mDNS
const char *myHostname = APP_NAME;

// DNS server
DNSServer dnsServer;

// Web server
ESP8266WebServer server(80);

#ifdef HAVE_SCREEN
  // Pour mise en veille de l'affichage, on le mettra à 0...
  uint8_t affichage_on = 1;
  long debutCompteurVeille = 0;
#endif

void IRAM_ATTR hall_ISR() {
  // Interruption du capteur à effet Hall
  if (digitalRead(HALL_PIN) == HIGH) {
    // Interruption front montant
    pulse++;
    #ifdef DEBUG_INTERRUPT
      ets_printf("hall_ISR() rising pulse = %d\n", pulse);
    #endif
  } else {
    // Interruption front descendant
    #ifdef DEBUG_INTERRUPT
      ets_printf("hall_ISR() falling pulse = %d\n", pulse);
    #endif
    ;
  }
}

void setup() {
  // Try pushing frequency to 160MHz.
  //bool update_cpu_freq = system_update_cpu_freq(160);
  // Set CPU frequency to 80MHz.
  bool update_cpu_freq = system_update_cpu_freq(80);

  #if defined(DEBUG) || defined(DEBUG_INTERRUPT) || defined(DEBUG2) || defined(DEBUG3) || defined(DEBUG_PROBE) || defined(DEBUG_WEB)
    Serial.begin(115200);
    Serial.setDebugOutput(true);
    Serial.flush();
    Serial.println();
    Serial.flush();
    int cpuFreq = system_get_cpu_freq();
    Serial.printf("\nStarting %s on ESP8266@%dMHz (system_update_cpu_freq() = %s)...\n\n", APP_NAME_VERSION, cpuFreq, update_cpu_freq?"true":"false");
    Serial.flush();
  #endif

  // Hardware init
  pinMode(HALL_PIN, INPUT);
  pinMode(CTN_PIN, INPUT);
  pinMode(LED_BUILTIN, OUTPUT);

  #ifdef HAVE_SCREEN
    // Init affichage
    affichage_init();
    afficheSplash();
  #endif

  // Récupération des paramètres EEPROM
  getEepromStartupData();

  // Capteur Température et pression
  bmp180_init();

  // Initialisation du WiFi
  wifiApInit();
  wifiClientInit();

  // Démarrage du serveur web
  webServerInit();

  // Interruptions pour détection Hall
  attachInterrupt(digitalPinToInterrupt(HALL_PIN), hall_ISR, CHANGE);

  #ifdef HAVE_SCREEN
    //Efface le logo par un scroll vers le haut
    scrollScreen();
    displayWifiStatus();
    delay(3000);
    debutCompteurVeille = millis();
  #endif

  delay(1000);
  digitalWrite(LED_BUILTIN, HIGH); // Eteint la LED

}

void loop() {
 
  temps1 = millis();

  // Lecture thermistor CTN
  if (nombreTemperature == 0) {
    temperatureCumule = readCtn();
  } else {
    temperatureCumule += readCtn();
  }
  nombreTemperature++;

  if (temps1 > temps0 + duree) {

    // Réinitialise le compteur de temps
    temps0 = temps1;
    
    #ifdef DEBUG2
      Serial.print("pulse = ");
      Serial.print(pulse);
      Serial.print(", duree = ");
      Serial.print(duree);
    #endif
    
    // Calcul du vent
    noInterrupts(); // Pour éviter que pulse change pendant le calcul
    vent = pulse * COEF_VENT; // TODO ecrire formule de calcul de la vitesse du vent = f(pulse)
    pulse = 0;
    interrupts(); // Réactive les interruptions

    // Correction en fonction de la duree
    vent = vent * DEFAULT_DUREE / duree;
    
    // Moyenne thermistor CTN sur la durée de mesure
    if (nombreTemperature != 0) {
      tempCtn = temperatureCumule / nombreTemperature;
    } else {
      tempCtn = readCtn();
    }
    nombreTemperature = 0;

    // Lecture du capteur de pression
    read_bmp180();

    #ifdef HAVE_SCREEN
      // Affichage sur écran
      displayTemp();
    #endif

    // Mémorise les 5 dernières minutes de mesures
    histVent[idxHistorique]       = vent;
    histBmp180[idxHistorique]     = tempBmp180;
    histPression[idxHistorique]   = pression;
    histTempCtn[idxHistorique++]  = tempCtn;
    if (idxHistorique > DUREE_HISTORIQUE) {
      idxHistorique = 0;
    }

    #ifdef DEBUG2
      Serial.print(", vent = ");
      Serial.print(vent);
      Serial.print(", temperature BMP180 = ");
      Serial.print(tempBmp180);
      Serial.print("°C, température CTN = ");
      Serial.print(tempCtn);
      Serial.print("°C, pression atmosphérique = ");
      Serial.print(pression);
      Serial.print("hPa\n");
    #endif
  }

  #ifdef HAVE_SCREEN
    if ((millis() > debutCompteurVeille + DELAY_VEILLE) && (affichage_on !=0)) {
      // Mise en veille
      #ifdef DEBUG
        Serial.println("Demande de mise en veille");
      #endif
      affichage_on = 0;
    }
  #endif

  // Process DNS
  dnsServer.processNextRequest();
  yield();
  delay(5);
  if (WiFi.status() == WL_CONNECTED) {
    MDNS.update();
  }
  yield();
  delay(5);
  // Process HTTP
  server.handleClient();
  yield();
  delay(5);

}

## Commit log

2024-05-16 FreeCAD model update
    [WeThermic.FCStd, WeThermic01.FCStd, WeThermic02-chapeau.stl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]
2024-05-17 Add FreeCAD STL
    [WeThermic-boitier.stl, WeThermic-chapeau.stl, WeThermic-juppeInf.stl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]
2024-05-27 ajout clipsage juppes
    [WeThermic-juppeInf.stl, WeThermic-juppeSup.stl, WeThermic.FCStd]
2024-05-28 Ajout plan pièces métalliques
    [WeThermic.FCStd]
2024-05-30 Add reset default setting button
2024-06-03 ajout butee rotation socle
    [WeThermic-socle.stl, WeThermic.FCStd]
2024-06-03 Change anemometer rotor for more efficiency
    [WeThermic.FCStd]
2024-06-03 Adding thread to upper bearing
2024-06-04 Add soft reboot function
    [webserver.cpp]
2024-06-08 correct wind bug + add display sleep
    [WeThermic.h, WeThermic.ino]
2024-06-13 Lower cpu freq for lower power consuption
2024-06-15 wakeup missing reply correction
    [webserver.cpp]
2024-08-05 Correct scan wifi bug when current SSID is not connected
    [webserver.cpp, wwwifi.cpp]
2024-08-06 Updated CAD and STL files
    [WeThermic-boitier.stl, WeThermic-chapeau.stl, WeThermic-fixationD1.stl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]
2024-08-07 on/off pictogram
    [WeThermic-boitier.stl]
2024-08-08 Adding ommited brideSwitch
    [WeThermic-brideSwitch.stl]
2024-08-08 Adding screw
    [WeThermic-vis.stl]
2024-08-09 Make more space inside for battery
    [WeThermic-boitier.stl, WeThermic-juppeSup.stl]
2024-08-10 Add pictures & screenshots
    [wethermic_logo.FCStd]
2024-08-11 Add GENERATE_204 option to avoid capture portal redirect on Android
    [WeThermic.h, webserver.cpp]
2024-08-11 Switch off the led ater startup
2024-08-11 Add pictures
    [WeThermic-boucheEcran.stl]
2024-08-19 add switch & lipo connection
2024-08-20 Update vis
    [WeThermic-vis.stl]
2025-01-20 Update FreeCAD model
    [WeThermic-boitier.stl, WeThermic-boucheEcran.stl, WeThermic-brideSwitch.stl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]
2025-01-25 Ajout fixeBatterie
    [WeThermic-fixeBatterie.stl]
2025-05-02 FreeCAD model adjust
    [WeThermic-juppeInf.stl, WeThermic-juppeSup.stl, WeThermic-rotor.stl]
